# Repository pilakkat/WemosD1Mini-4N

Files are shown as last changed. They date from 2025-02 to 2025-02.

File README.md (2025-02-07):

# Wemos D1 Mini 4 Node Smart Control

## 📌 Table of Contents

- [About the Project](#-about-the-project)
- [Screenshots](#-screenshots)
- [Usage](#-usage)
- [Configuration for Tasmota](#%EF%B8%8F-configuration-for-tasmota))

---

## 📖 About the Project

This board is designed as a multi-purpose board which can help in using the standard Wemos D1 Mini board based on ESP8266 to a 4 relay smart control unit. 
The relays are miniature in size which can control upto 5A, 250AC (or 7A, based on which unit you used). It has 4 inputs which can be connected to AC switch and 4 outputs can be connected to loads. The board can be fitted behind the switchboard as an after market fit without rewiring, provided there is a neutral line available. 

Additional taping points are added for using the device in many other configurations. Due to limited inputs, there is also 3 digital switch support based on ADC divider circuit provisioned. 

## 🖼 Screenshots

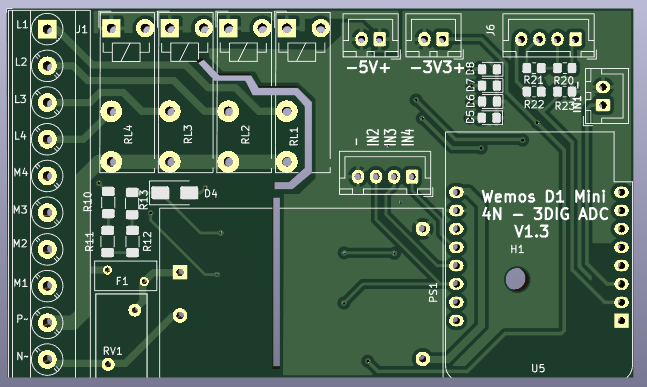
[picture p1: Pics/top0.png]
Top View - PCB

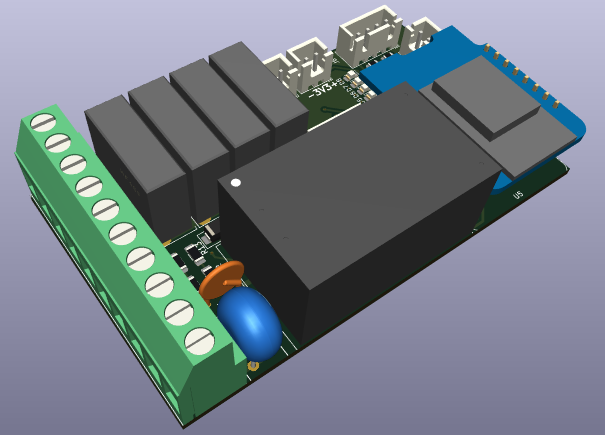
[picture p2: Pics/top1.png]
Top View 1

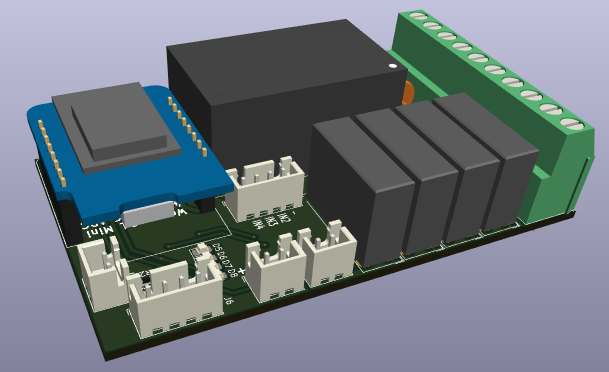
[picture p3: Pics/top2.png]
Top View 2


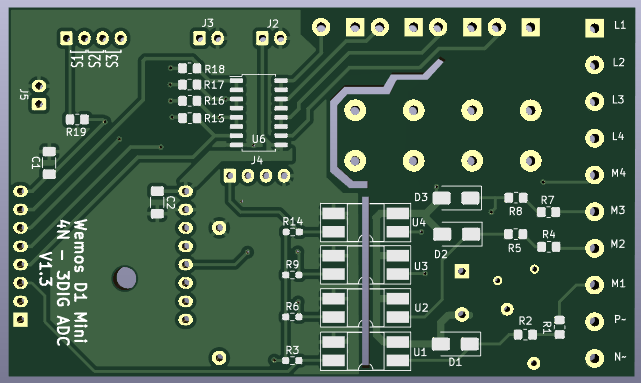
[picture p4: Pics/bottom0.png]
Bottom View - PCB

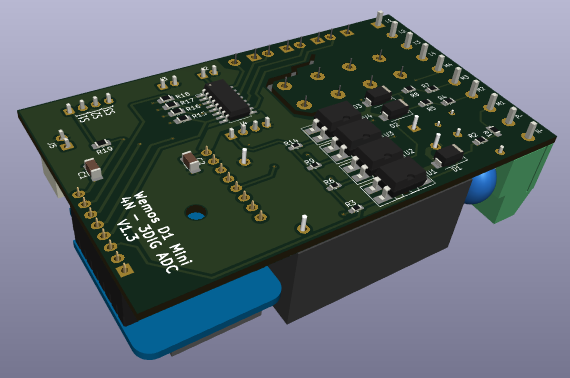
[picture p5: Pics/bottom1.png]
Bottom View 1


## 🚀 Usage
The design was done for using with Tasmota firmware, but user can use any firmware which can support the below configuraton.
- Inputs: D0, D1, D2, D3 and ADC (with voltage divider option for 3 digital pins)
- Outputs: D5, D5, D7 and D8

  Note: D3 has a pull-up and boot fails if pulled down during power on. 

D0 to D3 supports AC detection circuit. For using ADC divider based configuration, connect three switches between the marked joints (S1,S2,S3). All combinations of key presses and short circuits (SCB/SCG) are detectable via different ADC values if the default specified resistors are used. Other combinations could be used if only one or two switches are needed. 

Note: Refer BOM available under Gerber directory to see the component details.

## ⚙️ Configuration for Tasmota
Following configuration can be used for Tasmota firmware.

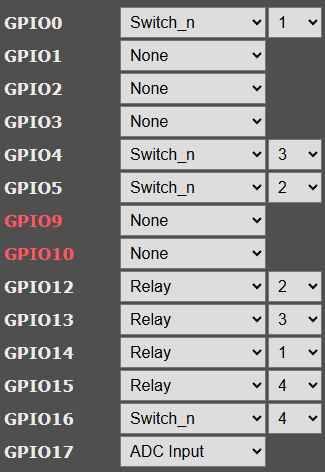
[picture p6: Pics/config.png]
Configuration for Tasmota devices


For AC detection circuit, you can also use following additional commands in tasmota console:
- switchdebounce0 109 : To set AC detection with 100ms debounce time
- switchmode0 1 : If you want to follow the manual switch instead of toggle every time

## 📜 License

This project is licensed under the MIT License

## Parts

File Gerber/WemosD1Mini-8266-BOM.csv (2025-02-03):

Id | Designator | Footprint | Quantity | Designation | Supplier and ref
1 | F1 | Fuse_BelFuse_0ZRE0005FF_L8.3mm_W3.8mm | 1 | Fuse
2 | U5 | WEMOS_D1_mini_light | 1 | WeMos_D1_mini
3 | RL3,RL1,RL2,RL4 | Relay_THT_Hongfa HF46F SPST | 4 | Relay_SPST-NO
4 | PS1 | Converter_ACDC_HiLink_HLK-5Mxx | 1 | HLK-5M05
5 | J5,J3,J2 | JST_XH_B2B-XH-A_1x02_P2.50mm_Vertical | 3 | Conn_01x02_Pin
6 | D4,D3,D1,D2 | D_SMA | 4 | 1N4007
7 | D7,D5,D6,D8 | LED_0805_2012Metric_Pad1.15x1.40mm_HandSolder | 4 | LED
8 | J8 | TerminalBlock_Phoenix_MKDS-3-8-5.08_1x08_P5.08mm_Horizontal | 1 | Screw_Terminal_01x08
9 | R12,R13,R11,R10 | R_1206_3216Metric_Pad1.30x1.75mm_HandSolder | 4 | 22K
10 | RV1 | RV_Disc_D12mm_W7.1mm_P7.5mm | 1 | Varistor
11 | R21 | R_0805_2012Metric_Pad1.20x1.40mm_HandSolder | 1 | 1K
12 | H1 | MountingHole_3.2mm_M3 | 1 | MountingHole
13 | J6,J4 | JST_XH_B4B-XH-A_1x04_P2.50mm_Vertical | 2 | Conn_01x04_Pin
14 | R23 | R_0805_2012Metric_Pad1.20x1.40mm_HandSolder | 1 | 1.5K
15 | R20,R19 | R_0805_2012Metric_Pad1.20x1.40mm_HandSolder | 2 | 470
16 | J1 | TerminalBlock_Phoenix_MKDS-3-10-5.08_1x10_P5.08mm_Horizontal | 1 | Screw_Terminal_01x10
17 | R22 | R_0805_2012Metric_Pad1.20x1.40mm_HandSolder | 1 | 2.2K
18 | R4,R8,R5,R7,R2,R1 | R_0805_2012Metric_Pad1.20x1.40mm_HandSolder | 6 | 180K
19 | R3,R9,R14,R6 | R_0603_1608Metric_Pad0.98x0.95mm_HandSolder | 4 | 10K
20 | U6 | SOP-16_4.4x10.4mm_P1.27mm | 1 | ULN2003
21 | R15,R17,R18,R16 | R_0805_2012Metric_Pad1.20x1.40mm_HandSolder | 4 | 150
22 | U4,U3,U2,U1 | DIP-4_W8.89mm_SMDSocket_LongPads | 4 | PC817
23 | C1,C2 | C_1206_3216Metric_Pad1.33x1.80mm_HandSolder | 2 | 0.1uF

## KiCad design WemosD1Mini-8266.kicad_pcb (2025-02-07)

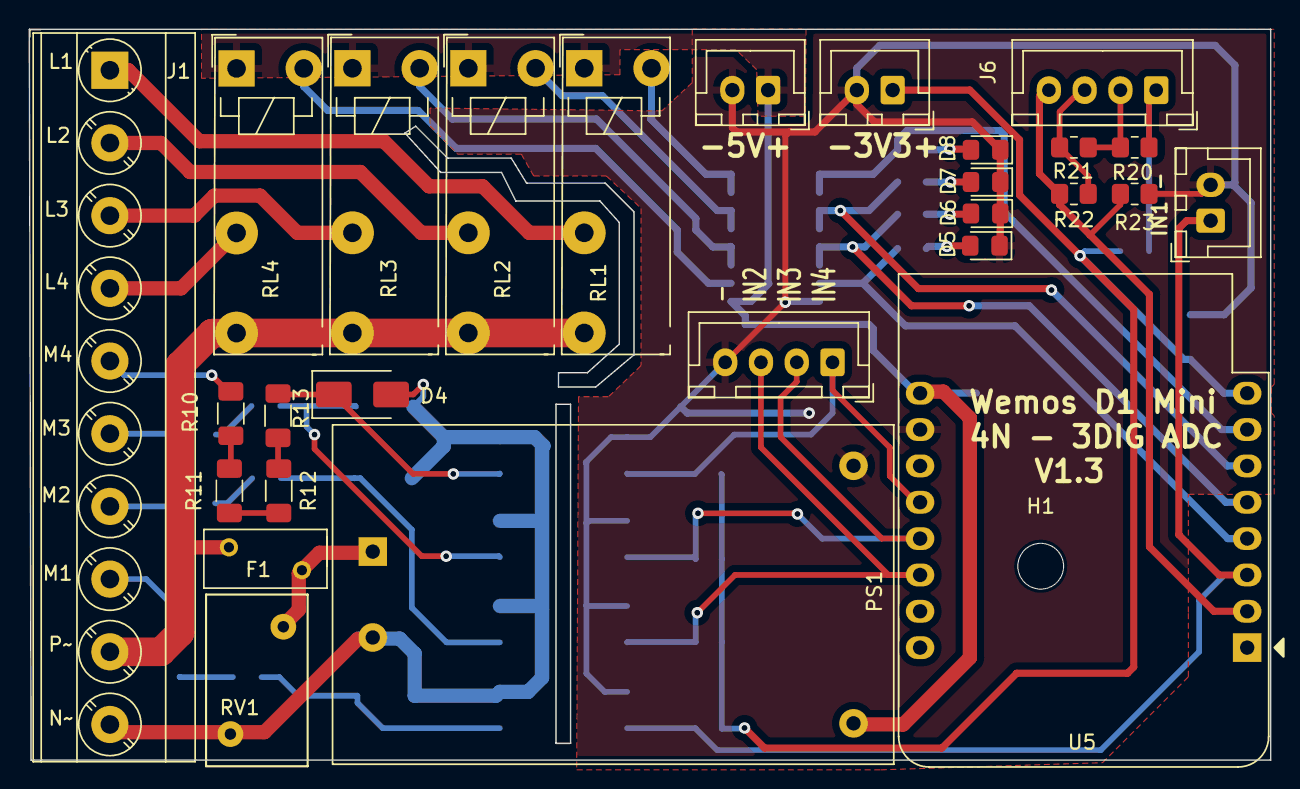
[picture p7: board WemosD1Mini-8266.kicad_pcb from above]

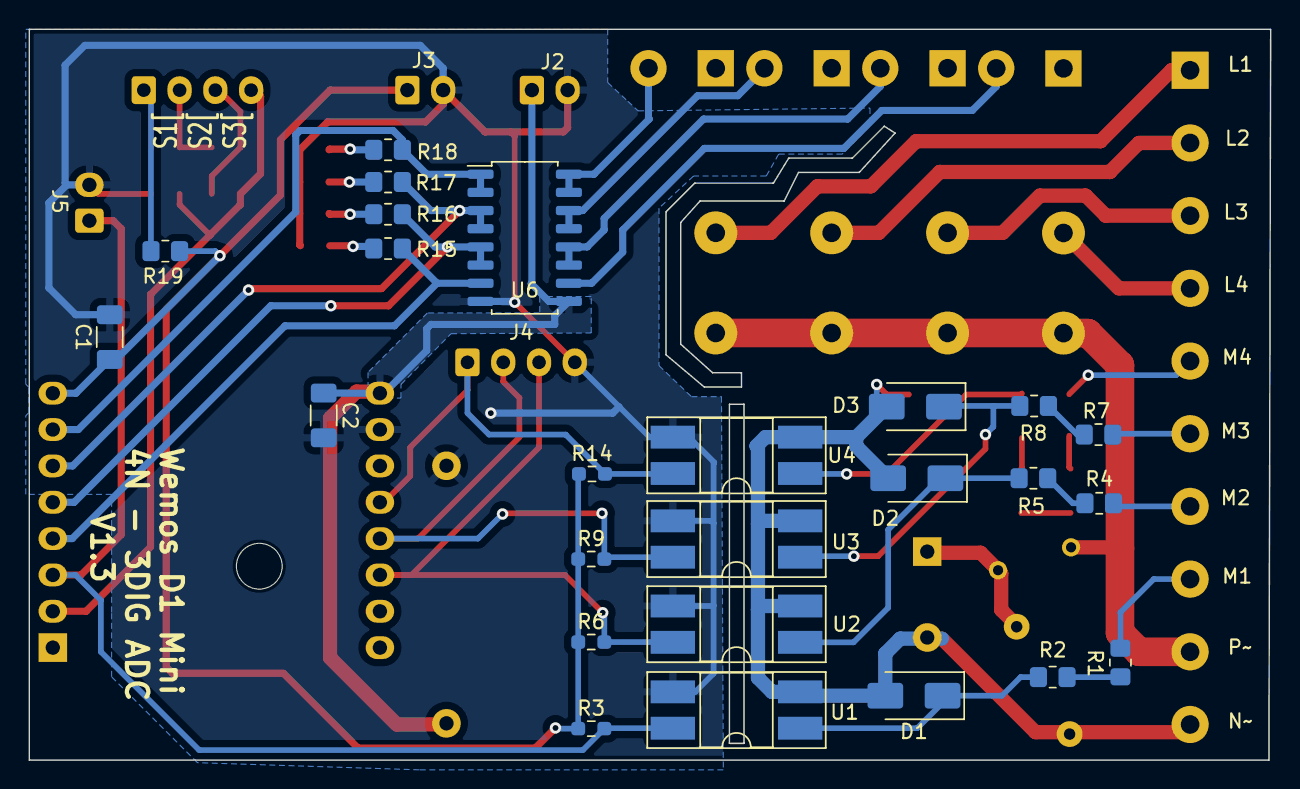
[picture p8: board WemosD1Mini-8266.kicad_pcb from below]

Board: 2 copper layers, 86.8 x 51.1 mm, 53 parts (25 on the bottom side), 44 nets.

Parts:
C1, C2: 0.1uF; C_1206_3216Metric_Pad1.33x1.80mm_HandSolder
D1, D2, D3, D4: 1N4007; D_SMA
D5, D6, D7, D8: LED; LED_0805_2012Metric_Pad1.15x1.40mm_HandSolder
F1: Fuse; Fuse_BelFuse_0ZRE0005FF_L8.3mm_W3.8mm
H1: MountingHole; MountingHole_3.2mm_M3
J1: Screw_Terminal_01x10; TerminalBlock_Phoenix_MKDS-3-10-5.08_1x10_P5.08mm_Horizontal
J2, J3, J5: Conn_01x02_Pin; JST_XH_B2B-XH-A_1x02_P2.50mm_Vertical
J4, J6: Conn_01x04_Pin; JST_XH_B4B-XH-A_1x04_P2.50mm_Vertical
PS1: HLK-5M05; Converter_ACDC_HiLink_HLK-5Mxx
R1, R2, R4, R5, R7, R8: 180K; R_0805_2012Metric_Pad1.20x1.40mm_HandSolder
R3, R6, R9, R14: 10K; R_0603_1608Metric_Pad0.98x0.95mm_HandSolder
R10, R11, R12, R13: 22K; R_1206_3216Metric_Pad1.30x1.75mm_HandSolder
R15, R16, R17, R18: 150; R_0805_2012Metric_Pad1.20x1.40mm_HandSolder
R19, R20: 470; R_0805_2012Metric_Pad1.20x1.40mm_HandSolder
R21: 1K; R_0805_2012Metric_Pad1.20x1.40mm_HandSolder
R22: 2.2K; R_0805_2012Metric_Pad1.20x1.40mm_HandSolder
R23: 1.5K; R_0805_2012Metric_Pad1.20x1.40mm_HandSolder
RL1, RL2, RL3, RL4: Relay_SPST-NO; Relay_THT_Hongfa HF46F SPST
RV1: Varistor; RV_Disc_D12mm_W7.1mm_P7.5mm
U1, U2, U3, U4: PC817; DIP-4_W8.89mm_SMDSocket_LongPads
U5: WeMos_D1_mini; WEMOS_D1_mini_light
U6: ULN2003; SOP-16_4.4x10.4mm_P1.27mm

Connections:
+3.3V: C1.1, J3.1, R3.1, R6.1, R9.1, R14.1, R19.2, U5.8 (3V3)
+5V: C2.1, J2.1, PS1.4 (+Vout), RL1.A1, RL2.A1, RL3.A1, RL4.A1, U5.9 (5V), U6.9 (COM)
/AC/L: F1.1, J1.9, RL1.14, RL2.14, RL3.14, RL4.14
/AC/L(P): F1.2, PS1.1 (AC/L), RV1.1
/AC/N: D1.2 (A), D2.2 (A), D3.2 (A), D4.2 (A), J1.10, PS1.2 (AC/N), RV1.2, U1.2, U2.2, U3.2, U4.2
/Load1: J1.4, RL4.13
/Load2: J1.3, RL3.13
/Load3: J1.2, RL2.13
/Load4: J1.1, RL1.13
/M1: J1.8, R1.1
/M2: J1.7, R4.1
/M3: J1.6, R7.1
/M4: J1.5, R10.1
/Relays/RL1: R15.1, U5.4 (SCK/D5), U6.7 (I7)
/Relays/RL2: R16.1, U5.5 (MISO/D6), U6.5 (I5), U6.6 (I6)
/Relays/RL3: R17.1, U5.6 (MOSI/D7), U6.3 (I3), U6.4 (I4)
/Relays/RL4: R18.1, U5.7 (CS/D8), U6.1 (I1), U6.2 (I2)
/Voltage Sensing/In1: J5.1, R3.2, U1.4, U5.3 (D0)
/Voltage Sensing/In2: J4.3, R6.2, U2.4, U5.14 (SCL/D1)
/Voltage Sensing/In3: J4.2, R9.2, U3.4, U5.13 (SDA/D2)
/Voltage Sensing/In4: J4.1, R14.2, U4.4, U5.12 (D3)
Earth: C1.2, C2.2, D5.1 (K), D6.1 (K), D7.1 (K), D8.1 (K), J2.2, J3.2, J4.4, J5.2, PS1.3 (-Vout), R23.2, U1.3, U2.3, U3.3, U4.3, U5.10 (GND), U6.8 (GND)
unnamed: D1.1 (K), R2.2, U1.1
unnamed: D2.1 (K), R5.2, U2.1
unnamed: D3.1 (K), R8.2, U3.1
unnamed: D4.1 (K), R13.2, U4.1
unnamed: D5.2 (A), R15.2
unnamed: D6.2 (A), R16.2
unnamed: D7.2 (A), R17.2
unnamed: D8.2 (A), R18.2
unnamed: J6.1, R19.1, R20.2
unnamed: J6.2, R20.1, R21.2
unnamed: J6.3, R21.1, R22.2
unnamed: J6.4, R22.1, R23.1, U5.2 (A0)
unnamed: R1.2, R2.1
unnamed: R4.2, R5.1
unnamed: R7.2, R8.1
unnamed: R10.2, R11.1
unnamed: R11.2, R12.1
unnamed: R12.2, R13.1
unnamed: RL1.A2, U6.15 (O2), U6.16 (O1)
unnamed: RL2.A2, U6.13 (O4), U6.14 (O3)
unnamed: RL3.A2, U6.11 (O6), U6.12 (O5)
unnamed: RL4.A2, U6.10 (O7)

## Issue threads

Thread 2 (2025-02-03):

AC Detection for switch 4 failing for some boards

pilakkat, 2025-02-03:
Some boards has no response for switch 4, connected to D3.

pilakkat, 2025-02-03:
D3 has a pull-up resistor which is causing the issue. 360K resistance at input side of PC817 is not providing sufficient current at the DC side when AC voltage is low, which causes the AC detection feature to fail. Using 100K - 150K resistance can solve the issue.

Closed 2025-02-03.

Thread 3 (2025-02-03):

Additional tapping for switch inputs required

pilakkat, 2025-02-03:
This is for reusing the board without AC detection (e.g. direct DC inputs from other detection circuits)

Closed 2025-02-03.

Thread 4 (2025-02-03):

Bypass circuit for temporary board removal

pilakkat, 2025-02-03:
If the board has to be removed from the switchboard for temporary fixes or for long term, additional bypass board can help immediate solution without rewiring.

Closed 2025-02-03.

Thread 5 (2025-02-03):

HV Protection missing

pilakkat, 2025-02-03:
Need to protect circuit from high voltages. Use MOV+Fuse combo

Closed 2025-02-03.

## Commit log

2025-02-03 Version 1
    [ACSens.kicad_sch, Relays.kicad_sch, Sensing.kicad_sch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]
2025-02-03 Version 1 Gerber Files
    [WemosD1Mini-8266-B_Cu.gbr, WemosD1Mini-8266-B_Mask.gbr, WemosD1Mini-8266-B_Paste.gbr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]
2025-02-03 Version 1.1
    [ACSens4R.kicad_sch, Relays.kicad_sch, Sensing.kicad_sch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]
2025-02-03 Version 1.2 Updates.
    Added support for 3 digital switches via ADC. Added MOV+Fuse protection
    [Relays.kicad_sch, VSensor.kicad_sch, VSensorInv.kicad_sch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]
2025-02-03 Gerber updates V1.2
    [WemosD1Mini-8266-BOM.csv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]
2025-02-03 missing pcb bottom view pic
2025-02-07 V1.3 - Removed bypass PCB due to single design mandate from manufacturing.
    [WemosD1Mini-8266-B_Cu.gbr, WemosD1Mini-8266-B_Mask.gbr, WemosD1Mini-8266-B_Paste.gbr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]
